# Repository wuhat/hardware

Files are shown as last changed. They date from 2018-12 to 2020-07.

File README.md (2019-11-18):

# WUHAT

A HAT for the Raspberry PI inspired by the
[franzboard](https://github.com/franzboard) and compatible in terms of switch
and LED connections.

## Features

* 1 DS18B20 temperature sensor
* 3 tactile switches
* 4 LEDs
* 1 ADC with 2 channels accessible via a header
* 6 GPIO pins on a header, surrounded by GND, 5V, and 3.3V
* 1 I2C pin header (GND SDA SCL 3V3)

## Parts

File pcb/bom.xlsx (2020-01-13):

Stk | Description | RS-Components.at Nr.
1 | Pin Header Female 2.54mm 2x20 | 674-2369 (https://at.rs-online.com/web/p/leiterplatten-buchsen/6742369/)
8 | Pin Header Male 2.54mm 1x4 | 681-2979 (https://at.rs-online.com/web/p/leiterplatten-header/6812979)
1 | Pin Header Male 2.54mm 1x3 | 681-2975 (https://at.rs-online.com/web/p/leiterplatten-header/6812975)
5 | 1k 0603 | 807-5380 (https://at.rs-online.com/web/p/smd-widerstande/8075380/)
2 | 3k9 0603 | 807-5550 (https://at.rs-online.com/web/p/smd-widerstande/8075550/)
15 | 4k7 0603 | 807-5579 (https://at.rs-online.com/web/p/smd-widerstande/8075579/)
1 | 1uF 0603 | 172-1482 (https://at.rs-online.com/web/p/keramik-vielschichtkondensatoren/1721482)
4 | LED 0603 | 861-0100 (https://at.rs-online.com/web/p/led/8610100/)
3 | Tactile Switches 6x6mm | 135-9508 (https://at.rs-online.com/web/p/tastschalter/1359508)
1 | DS18S20 TO-92 | 540-2849 (https://at.rs-online.com/web/p/temperatursensoren-und-feuchtigkeitssensoren/5402849)
1 | MCP3002 SOIC-8 3.9x4.9mm | 669-6058 (https://at.rs-online.com/web/p/a-d-wandler/6696058)
1 | CAT24C256 SOIC-8 3.9x4.9mm | 808-0199 (https://at.rs-online.com/web/p/eeproms/8080199/)

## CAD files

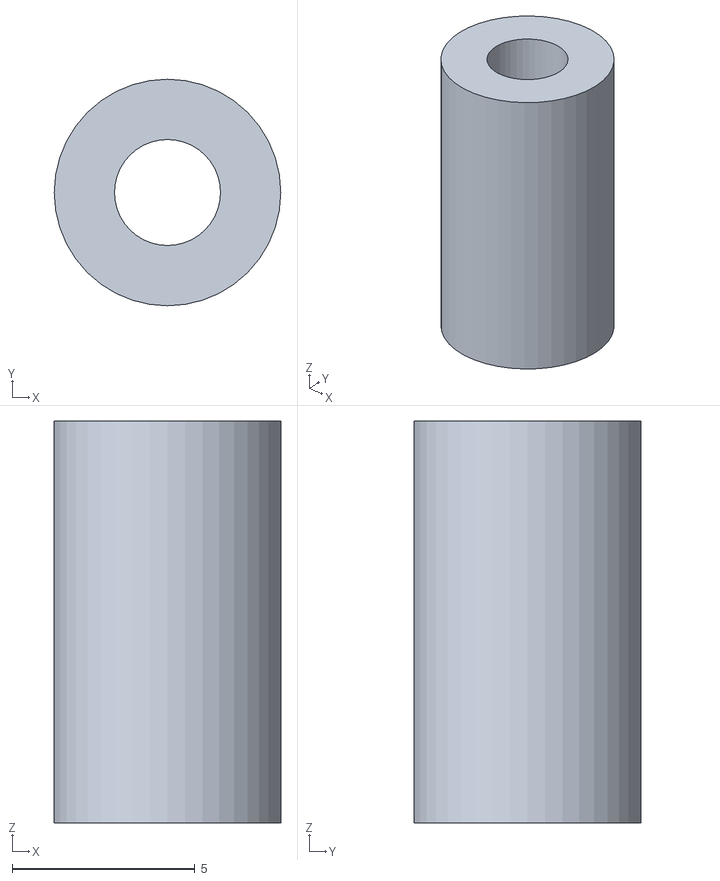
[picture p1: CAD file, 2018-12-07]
mechanical/spacer.stl
6.20 x 6.20 x 11.0

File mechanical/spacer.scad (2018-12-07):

module spacer(){
    difference(){
        cylinder(d=6.2, h=11);
        translate([0,0,-0.5])cylinder(d=2.9, h=12);
    }
}

$fn=40;
spacer();

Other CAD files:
pcb/pi_zero_outline/pi_zero_outline.fcstd
pcb/pi_zero_outline/pi_zero_outline.dxf

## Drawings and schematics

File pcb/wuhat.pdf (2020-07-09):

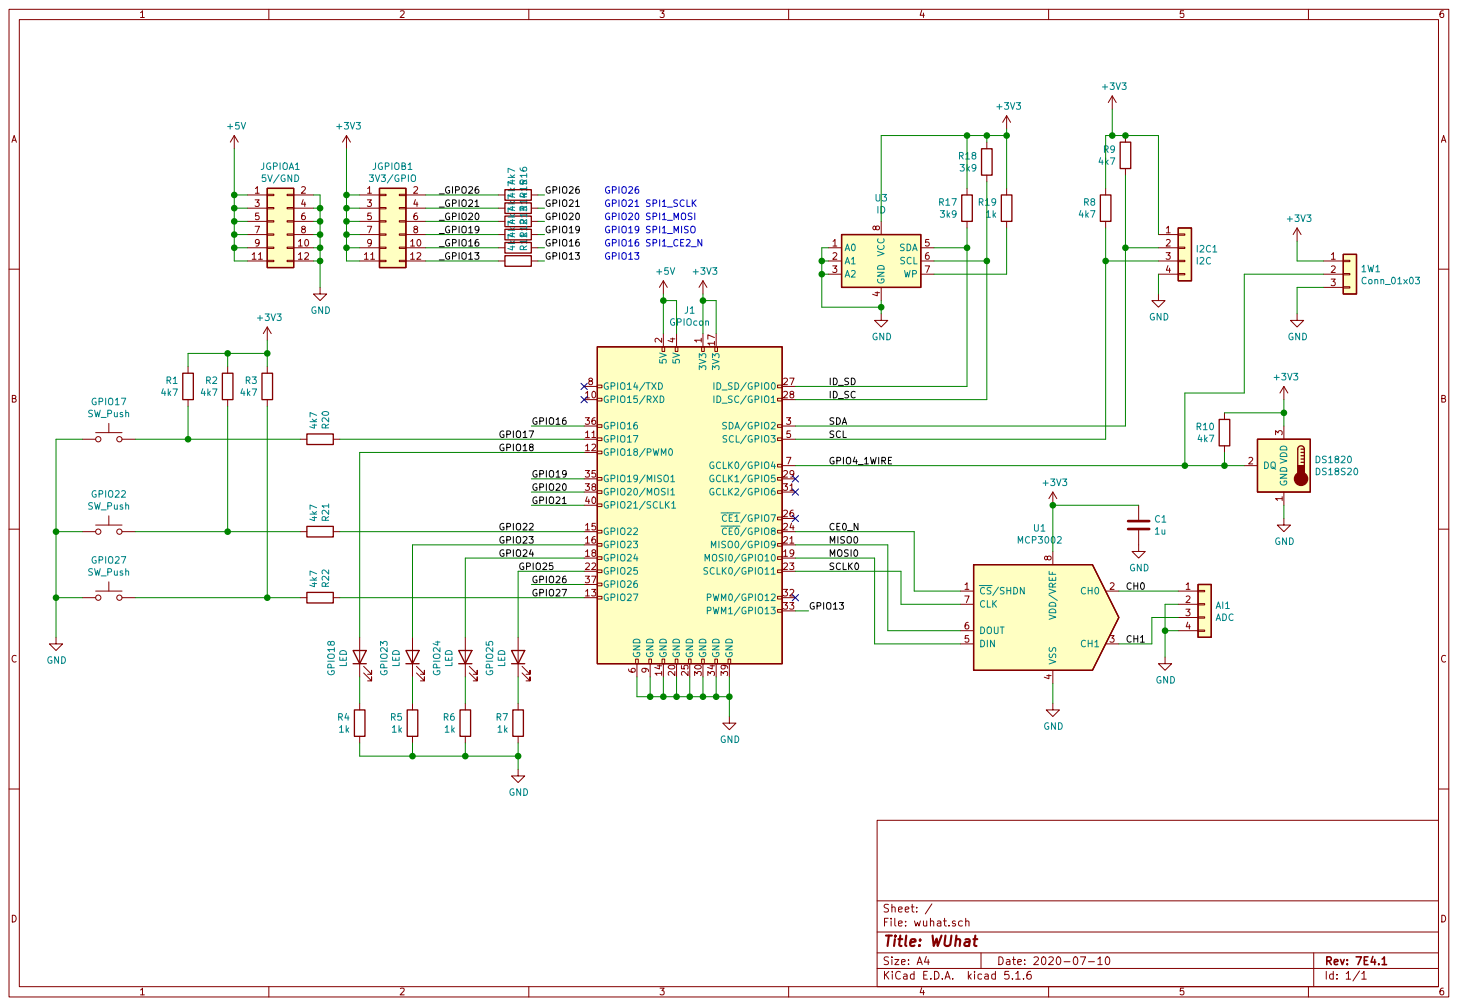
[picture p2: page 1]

4 SDA 5 SCL 6 WP 7 VCC

4 DIN 5 DOUT 6 CLK 7 VDD/VREF

Id: 1/1 Title: WUhat File: wuhat.sch Sheet: /

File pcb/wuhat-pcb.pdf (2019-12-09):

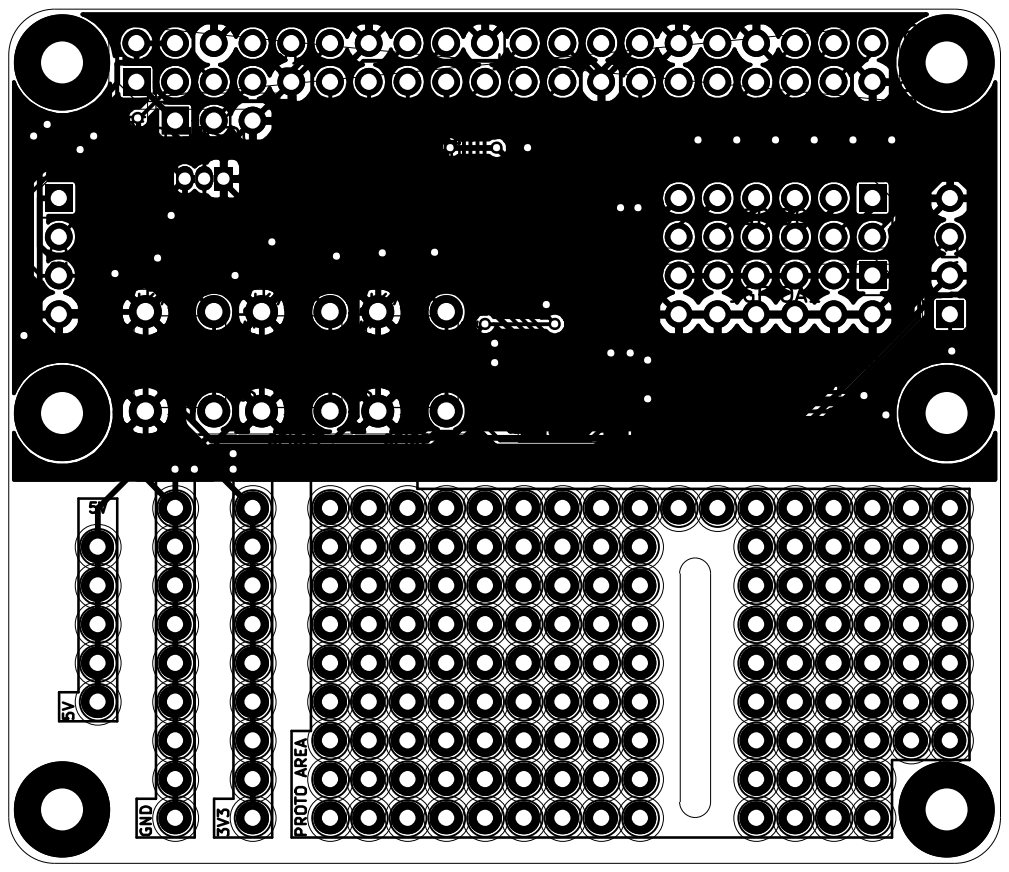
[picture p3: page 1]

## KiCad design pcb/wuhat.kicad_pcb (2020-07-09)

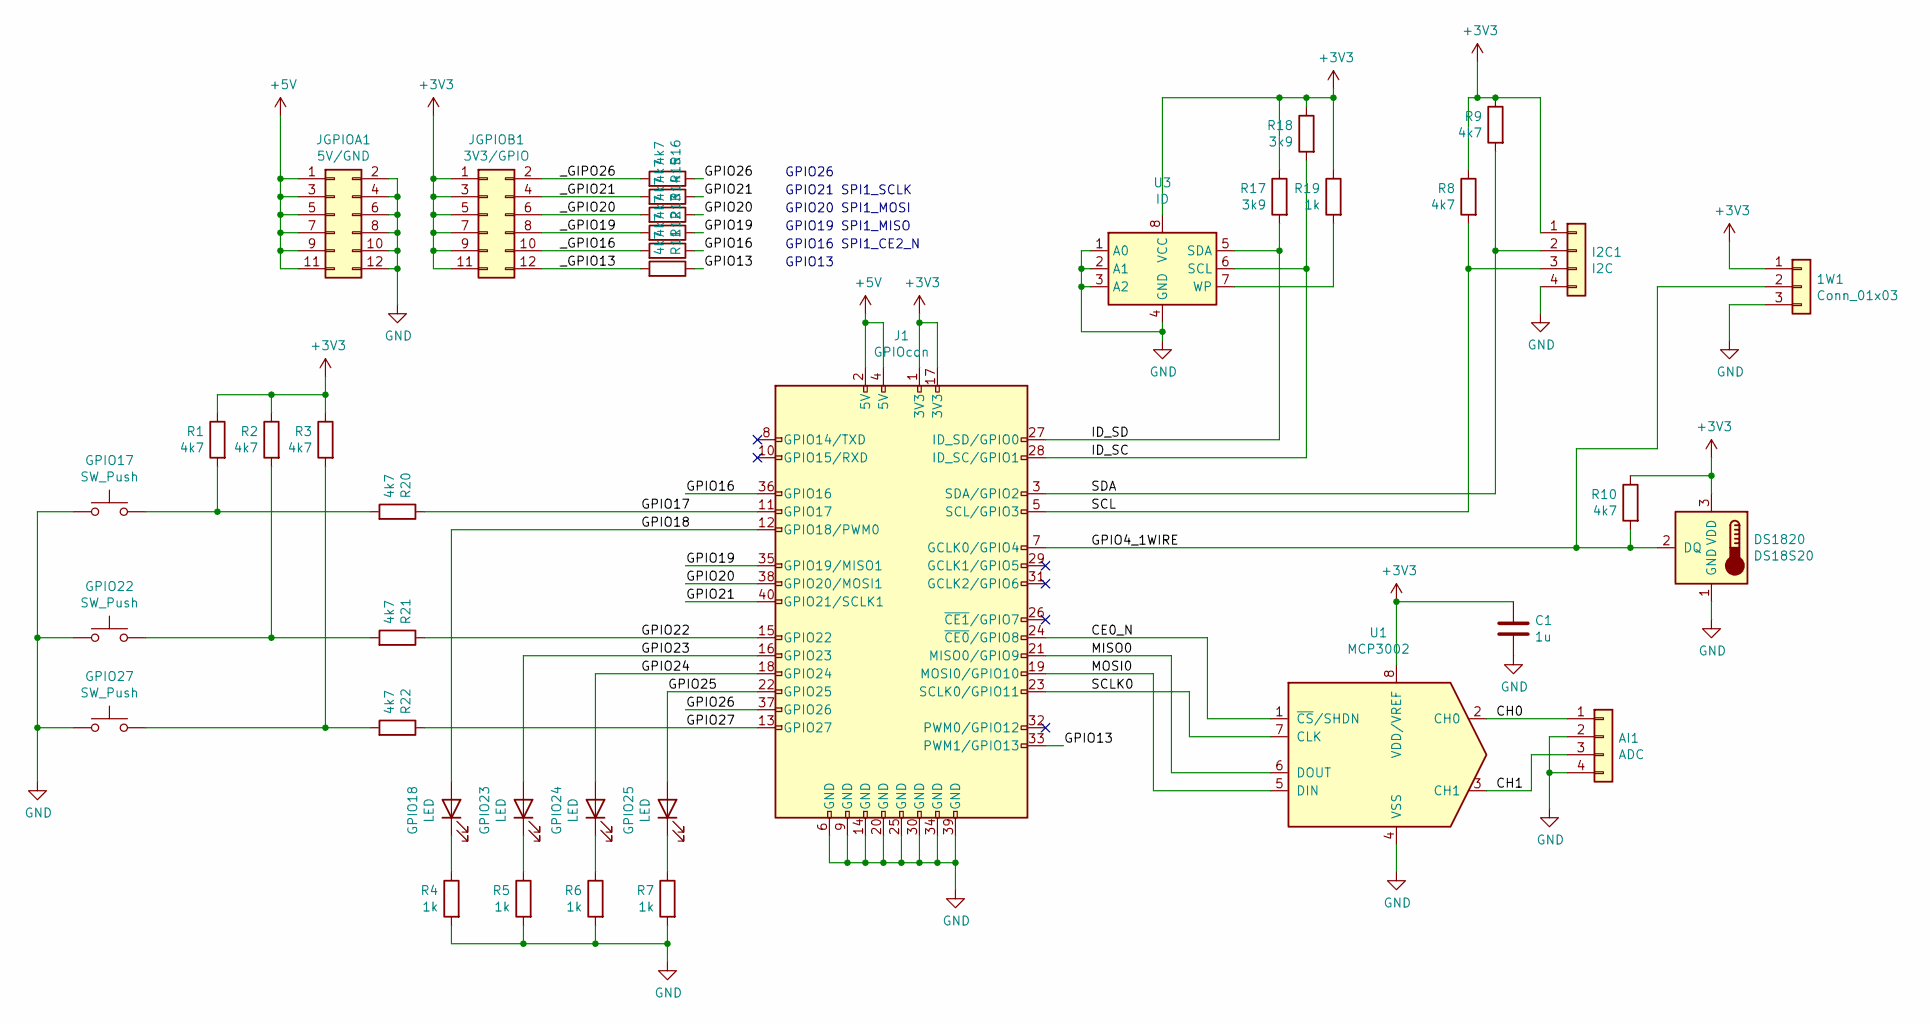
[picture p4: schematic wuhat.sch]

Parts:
1W1: Conn_01x03; PinHeader_1x03_P2.54mm_Vertical
AI1: ADC; PinHeader_1x04_P2.54mm_Vertical
C1: 1u; C_0603_1608Metric_Pad1.05x0.95mm_HandSolder
DS1820: DS18S20; TO-92_Inline_Wide
GPIO17, GPIO22, GPIO27: SW_Push; SW_PUSH_6mm
GPIO18, GPIO23, GPIO24, GPIO25: LED; LED_0603_1608Metric_Pad1.05x0.95mm_HandSolder
I2C1: I2C; PinHeader_1x04_P2.54mm_Vertical
J1: GPIOcon; PinHeader_2x20_P2.54mm_Vertical
JGPIOA1: 5V/GND; PinHeader_2x06_P2.54mm_Vertical
JGPIOB1: 3V3/GPIO; PinHeader_2x06_P2.54mm_Vertical
R1, R2, R3, R8, R9, R10, R11, R12, R13, R14, R15, R16, R20, R21, R22: 4k7; R_0603_1608Metric_Pad1.05x0.95mm_HandSolder
R4, R5, R6, R7, R19: 1k; R_0603_1608Metric_Pad1.05x0.95mm_HandSolder
R17, R18: 3k9; R_0603_1608Metric_Pad1.05x0.95mm_HandSolder
U1: MCP3002; SOIC-8_3.9x4.9mm_P1.27mm
U3: ID; SOIC-8_3.9x4.9mm_P1.27mm

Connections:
+3V3: 1W1.1, C1.1, DS1820.3 (VDD), I2C1.1, J1.1 (3V3), J1.17 (3V3), JGPIOB1.1, JGPIOB1.3, JGPIOB1.5, JGPIOB1.7, JGPIOB1.9, JGPIOB1.11, R1.1, R2.1, R3.1, R8.1, R9.1, R10.1, R17.1, R18.1, R19.1, U1.8 (VDD/VREF), U3.8 (VCC)
+5V: J1.2 (5V), J1.4 (5V), JGPIOA1.1, JGPIOA1.3, JGPIOA1.5, JGPIOA1.7, JGPIOA1.9, JGPIOA1.11
/CE0_N: J1.24 (~CE0~/GPIO8), U1.1 (~CS~/SHDN)
/CH0: AI1.1, U1.2 (CH0)
/CH1: AI1.3, U1.3 (CH1)
/GPIO4_1WIRE: 1W1.2, DS1820.2 (DQ), J1.7 (GCLK0/GPIO4), R10.2
/GPIO13: J1.33 (PWM1/GPIO13), R11.1
/GPIO16: J1.36 (GPIO16), R12.1
/GPIO17: J1.11 (GPIO17), R20.1
/GPIO18: GPIO18.2 (A), J1.12 (GPIO18/PWM0)
/GPIO19: J1.35 (GPIO19/MISO1), R13.1
/GPIO20: J1.38 (GPIO20/MOSI1), R14.1
/GPIO21: J1.40 (GPIO21/SCLK1), R15.1
/GPIO22: J1.15 (GPIO22), R21.1
/GPIO23: GPIO23.2 (A), J1.16 (GPIO23)
/GPIO24: GPIO24.2 (A), J1.18 (GPIO24)
/GPIO25: GPIO25.2 (A), J1.22 (GPIO25)
/GPIO26: J1.37 (GPIO26), R16.1
/GPIO27: J1.13 (GPIO27), R22.1
/ID_SC: J1.28 (ID_SC/GPIO1), R18.2, U3.6 (SCL)
/ID_SD: J1.27 (ID_SD/GPIO0), R17.2, U3.5 (SDA)
/MISO0: J1.21 (MISO0/GPIO9), U1.6 (DOUT)
/MOSI0: J1.19 (MOSI0/GPIO10), U1.5 (DIN)
/SCL: I2C1.3, J1.5 (SCL/GPIO3), R8.2
/SCLK0: J1.23 (SCLK0/GPIO11), U1.7 (CLK)
/SDA: I2C1.2, J1.3 (SDA/GPIO2), R9.2
/_GIPO26: JGPIOB1.2, R16.2
/_GPIO13: JGPIOB1.12, R11.2
/_GPIO16: JGPIOB1.10, R12.2
/_GPIO19: JGPIOB1.8, R13.2
/_GPIO20: JGPIOB1.6, R14.2
/_GPIO21: JGPIOB1.4, R15.2
GND: 1W1.3, AI1.2, AI1.4, C1.2, DS1820.1 (GND), GPIO17.1, GPIO22.1, GPIO27.1, I2C1.4, J1.6 (GND), J1.9 (GND), J1.14 (GND), J1.20 (GND), J1.25 (GND), J1.30 (GND), J1.34 (GND), J1.39 (GND), JGPIOA1.2, JGPIOA1.4, JGPIOA1.6, JGPIOA1.8, JGPIOA1.10, JGPIOA1.12, R4.2, R5.2, R6.2, R7.2, U1.4 (VSS), U3.1 (A0), U3.2 (A1), U3.3 (A2), U3.4 (GND)
unnamed: GPIO17.2, R1.2, R20.2
unnamed: GPIO18.1 (K), R4.1
unnamed: GPIO22.2, R2.2, R21.2
unnamed: GPIO23.1 (K), R5.1
unnamed: GPIO24.1 (K), R6.1
unnamed: GPIO25.1 (K), R7.1
unnamed: GPIO27.2, R3.2, R22.2
unnamed: R19.2, U3.7 (WP)

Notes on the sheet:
GPIO21 SPI1_SCLK
GPIO20 SPI1_MOSI
GPIO26
GPIO16 SPI1_CE2_N
GPIO19 SPI1_MISO
GPIO13

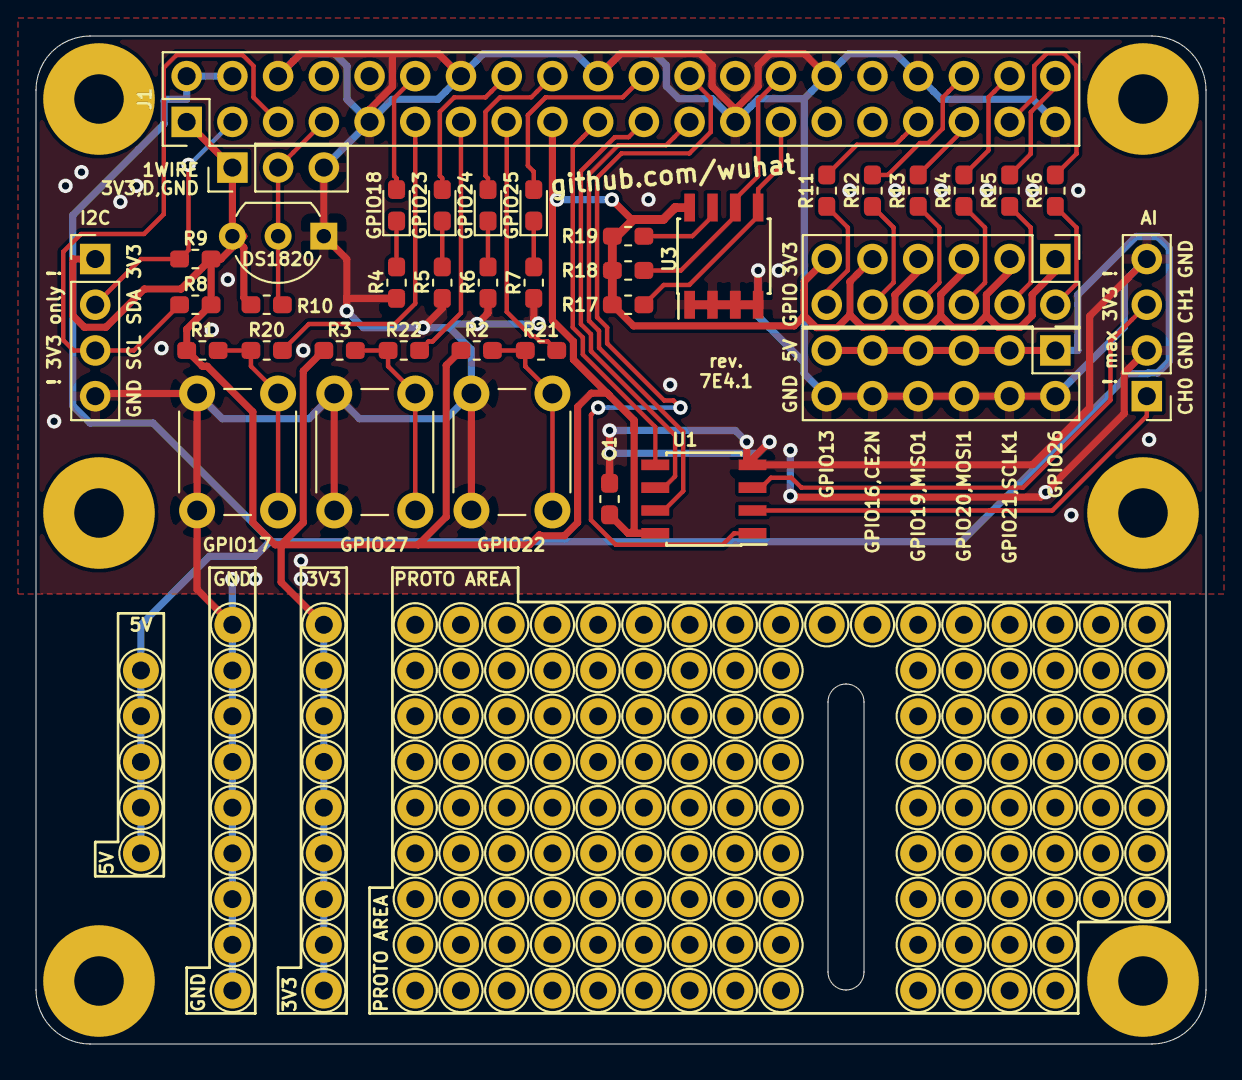
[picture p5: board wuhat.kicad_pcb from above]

Board: 2 copper layers, 65.0 x 56.0 mm, 42 parts (1 on the bottom side), 41 nets.

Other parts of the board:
LOGO: qrcode
e: mounting_hole
e#2: mounting_hole

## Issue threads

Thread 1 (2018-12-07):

Allow to disable write protect for the ID EEPROM

chbw, 2018-12-07:
Currently, the ID EEPROM is always write protected. One needs a pull down the EEPROM pin with a needle probe or similar to disable the write protection. The schematic segment located at https://github.com/raspberrypi/hats/blob/master/eeprom-circuit.png shows how a jumper could be used to enable programming of the ID EEPROM after soldering it to the wuhat. Even if the pin header is not populated, the availability of the pads would ease programming.

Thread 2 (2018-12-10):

missing revision number on board

chbw, 2018-12-10:
The first revision does not have a revision number on the silk screen

chbw, 2019-12-09:
has been added

Closed 2019-12-09.

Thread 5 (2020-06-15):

DS1820 footprint difficult to hand solder

chbw, 2020-06-15:
A larger footprint (more space between pins) should lead to nicer boards and less troubleshooting.

chbw, 2020-07-09:
fixed

Closed 2020-07-09.

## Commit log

2018-12-04 first prototype run
    [pi_zero_outline.dxf, pi_zero_outline.fcstd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]
2018-12-04 added schematic pdf
2018-12-07 added spacers
    [spacer.scad, spacer.stl]
2019-11-18 added revision string to pcb
    bumped the revision to 7E4.0 (hex for 2020.0).
    [wuhat.kicad_pcb, wuhat.sch]
2019-12-05 BOM added
2019-12-09 expanded board to full size hat
    [wuhat-B.Cu.gbr, wuhat-B.Mask.gbr, wuhat-B_Cu.gbr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]
2019-12-09 updated pdfs
    [wuhat.kicad_pcb]
2019-12-09 BOM updated and converted to xlsx
    [bom.xlsx]
2020-01-13 fixed eeprom in bom
    [bom.xlsx]
2020-07-09 modified DS1820 footprint
    [wuhat-B_Cu.gbr, wuhat-B_Mask.gbr, wuhat-B_SilkS.gbr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]
